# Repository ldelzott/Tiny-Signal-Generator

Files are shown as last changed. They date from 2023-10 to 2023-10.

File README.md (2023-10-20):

# Hobby-grade micro (PWM) signal generator made with off-the-shelve components
(Made in january 2023)

PWM signal generator based on an ESP32 microcontroller. The user can configure and customize individually each of the 16 PWM signals generated "simultaneously" by the device. The configuration is done via a physical & software user interface made of 4 push buttons and a 1.3" screen displaying a custom GUI. The electronic is encased in a 3D-printed plastic shell. The device can power standard 5mm LEDs or small servo motors (e.g. TowerPro SG90).  

## Plastic shell
The plastic pieces and the electronic are held together by friction. The pieces can be printed without any supports. 

platic_pieces

* A - gen_back_case.step
* B - gen_screen_upper_holder.step
* C - gen_screen_holder.step
* D - gen_pcb_separation.step
* E - gen_keypad_holder.step
* F - gen_keypad_lower_holder.step
* G - gen_front_case.step

## Electronic 
### Components
* [[DOC](https://docs.espressif.com/projects/esp-idf/en/latest/esp32/hw-reference/esp32/get-started-devkitc.html)] [[Components](https://www.amazon.fr/gp/aw/d/B071P98VTG/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)] ESP32-WROOM-32 Dev Kit C
* [DOC] [[Components](https://www.amazon.fr/daffichage-polychrome-cristaux-liquides-dentraînement/dp/B07QGQ1SR2/ref=sr_1_6?keywords=IPS+1.3"+240x240+with+ST7789&qid=1697656905&sr=8-6)] IPS 1.3" 240x240 with ST7789 controller.
* [DOC] [[Components](https://www.amazon.fr/ARCELI-Interface-IIC-Blindage-Raspberry/dp/B07RG9ZTMD/ref=sr_1_5?__mk_fr_FR=ÅMÅŽÕÑ&crid=3J0AZ9PUXPUG1&keywords=PCA9685+breakout+board&qid=1697656927&sprefix=pca9685+breakout+board%2Caps%2C59&sr=8-5)] PCA9685 breakout board
* [DOC] [[Components](https://www.amazon.fr/ARCELI-Interface-IIC-Blindage-Raspberry/dp/B07RG9ZTMD/ref=sr_1_5?__mk_fr_FR=ÅMÅŽÕÑ&crid=3J0AZ9PUXPUG1&keywords=PCA9685+breakout+board&qid=1697656927&sprefix=pca9685+breakout+board%2Caps%2C59&sr=8-5)] 4 Push buttons

### Schematic (draft)
wire_diagram_draftpng

### Specifications
Generate 16 PWM signals of 12-Bit at 1KHz, the PWM is reduced to 50Hz when at least one servo motor is attached & used.
When not disturbed by any user input, the generator outputs 50 points per second for each signal (50x16 points per second for the 16 signals). Each signal is made of 2048 points.   
## Overview
The device with the front case removed:

overview

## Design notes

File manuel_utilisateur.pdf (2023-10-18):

# Manuel

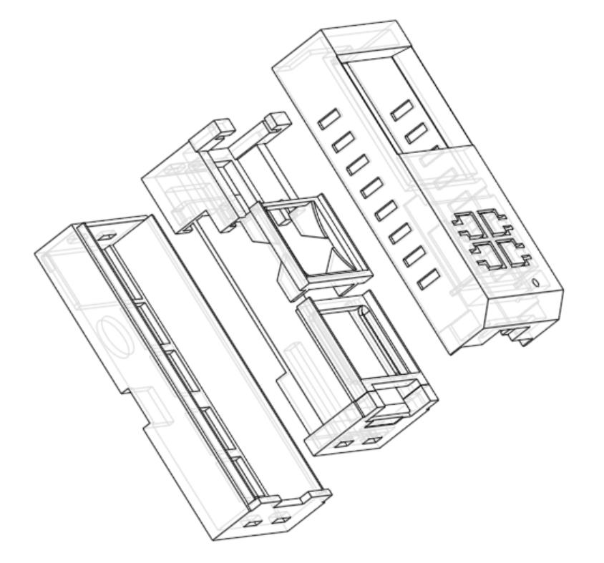
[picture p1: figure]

# Générateur de signaux 16-canaux pour LEDs & servo-moteurs

## Table des matières

## Intention

L’appareil permet de gérer jusqu’à 16 lumières (LEDs) et/ou moteurs à position programmable (SERVOs). Dans l’exemple d’une maquette d’avion, l’appareil peut être utilisé pour programmer le mouvement des volets ainsi que la séquence lumineuse des témoins de position. Il peut encore être utilisé pour réaliser des effets combinant lumières et/ou mouvements tel qu’un feu, ou encore animer des portes automatiques, des barrières, etc.

Note : l’appareil a pour vocation de permettre l’expérimentation dès lors qu’un mouvement ou un éclairage est requis pour une scène donnée. L’appareil ne devrait pas être utilisé comme une solution permanente.

## Informations complémentaires

Le générateur de signaux 16-canaux est un assemblage de pièces de plastique et de composants électroniques. Ces composants sont listés ci-après.

- Une carte de développement ESP32-WROOM-32 Dev Kit C.
- Un module d’affichage IPS 1.3’’ 240x240 pixels avec contrôleur ST7789 et interface SPI.
- Un module proposant 16 canaux PWM avec microcontrôleur PCA9685 et interface I2C.
- Un circuit comportant 4 boutons poussoir.

Un fois alimenté, l’assemblage permet de générer jusqu’à 16 signaux PWM simultanément. Chaque signal, configuré individuellement, est généré indépendamment des autres signaux. La configuration d’un signal s’effectue via l’écran et les boutons poussoir présent sur la face avant.

Note : PWM = Pulse Width Modulation.

## Alimentation

### Alimentation via port USB

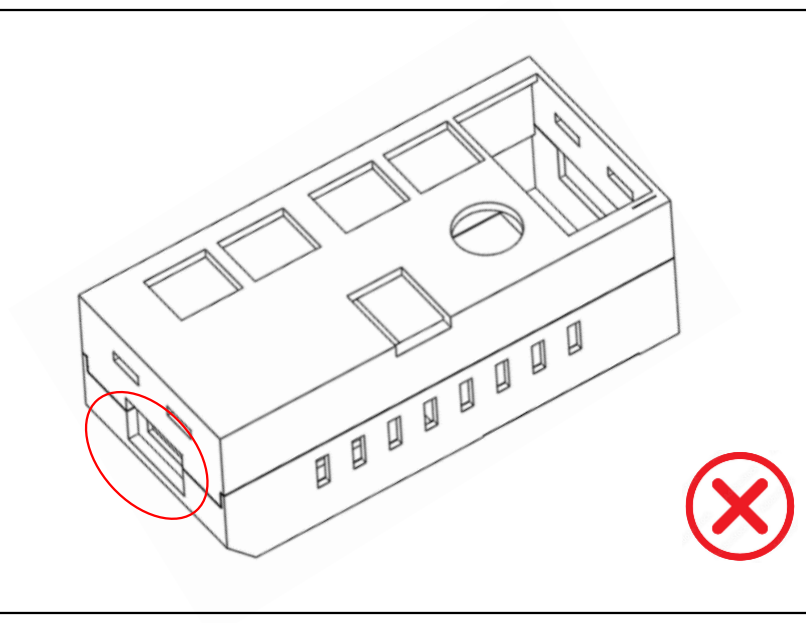
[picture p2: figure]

Le port USB permet de mettre à jour l’appareil. Le port USB ne doit pas être branché lors de l’utilisation : l’alimentation de l’appareil doit s’effectuer par le serre-fils (sucre) vert situé sur sa face arrière.

### Alimentation via serre-fils

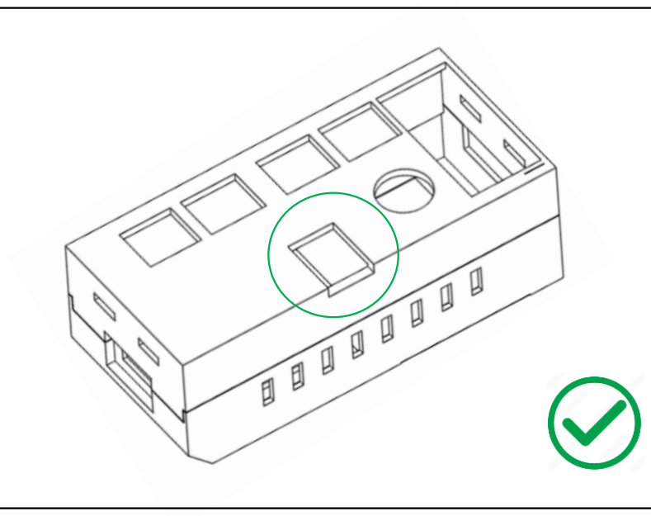
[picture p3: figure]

Le générateur doit être raccordé à une source de tension de 5V (continue) via le serre-fils vert. La borne de terre/masse est mise en surbrillance à l’indélébile noir. La consommation électrique de l’appareil varie en fonction du nombre de LED et/ou servo-moteurs connectés. Lorsque aucun composant ne lui est connecté, l’appareil consomme environ 110 mA.

### Dommages irréversibles en cas d’inversion de polarité

L’appareil n’est pas protégé contre les inversions de polarité.

## Branchements des composants

Le branchement des composants s’effectue via les ports situés sur la face arrière de l’appareil.

### Identification des ports

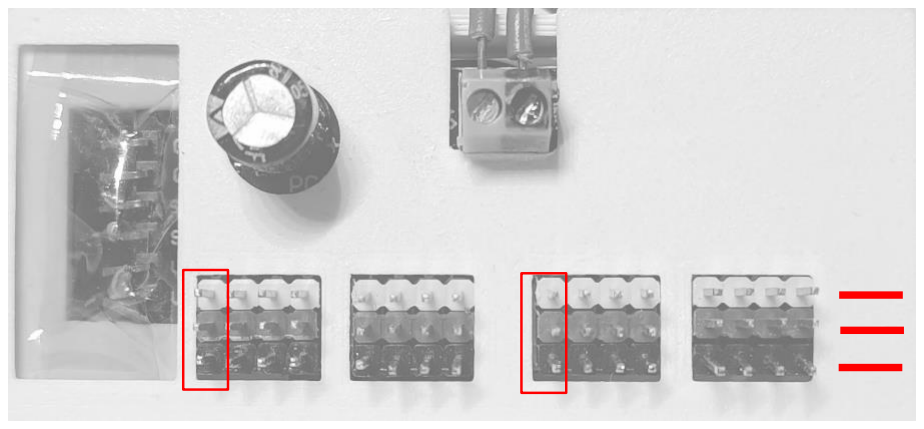
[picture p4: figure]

### Exemple de connexion – LED 5mm classique

La cathode (-) et l’anode (+) se connecte respectivement à la broche noire et jaune d’un port.

### Exemple de connexion – Servo moteur TowerPro SG90

Le fil brun, rouge et jaune du servo moteur se connecte respectivement à la broche noire, rouge et jaune d’un port.

### Caractéristiques technique des ports

En théorie, un port ne peut délivrer un courant supérieur à 25mA. Cette limite, fournie par le fabricant d’un des modules qui constitue l’appareil, n’a pas été testée en pratique. Idéalement, le branchement d’un composant ne devrait se faire qu’après configuration et vérification du signal généré sur un port donné.

0V (noir)

Port 1 | Port 9

5V 0V

5V (rouge)

PWM (jaune)

## Navigation

Description de la fonction de chaque bouton poussoir.

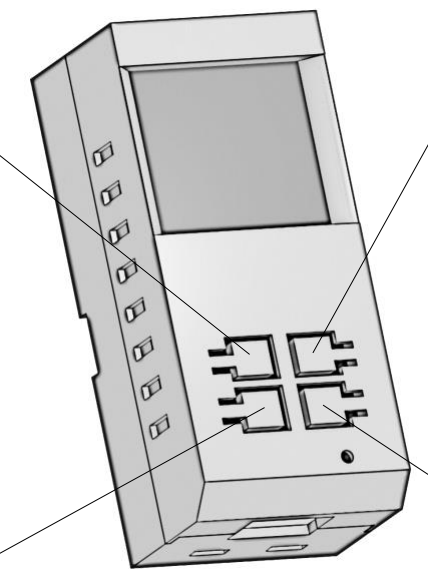
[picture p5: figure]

## Configurer un signal (pour LED/Lumière)

Cette section décrit les étapes nécessaires à la configuration d’un nouveau signal pour le port 1.

Example – Créer un signal sinusoïdal sur le port 1.
La touche NAV est utilisée pour parcourir les éléments des menus. La touche SELECT/DIV sélectionne l’élément souhaité.
1. Dans le menu principal, la « scene » fait référence à l’ensemble des signaux générés.
2. Les ports sont numérotés de 1 à 16. A chaque port est associée 3 broches visibles sur la face arrière.

NAV

Les différents éléments qui constituent un menu sont
accessibles par appuis
répétés sur la touche de
navigation

MINUS(-)
Lorsque l’élément mis en
surbrillance comporte un champ de valeur, la touche minus (-) réduit la valeur correspondante.

SELECT/DIV

Permet de sélectionner un élément. Lorsque l’élément comporte un champ de valeur, la fonction DIV permet de modifier la quantité ajoutée/retirée par les touches MINUS(-)/PLUS(+).

PLUS(+)

Lorsque l’élément
sélectionné comporte un
champ de valeur, la touche plus (+) augmente la valeur correspondante.

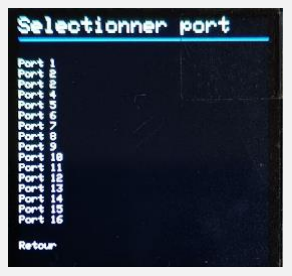
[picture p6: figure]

3. Le choix du port est effectué par appuis successifs sur la touche NAV.

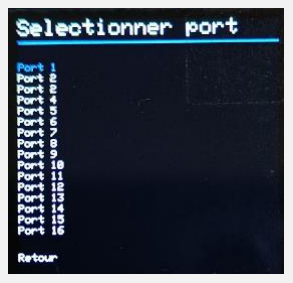
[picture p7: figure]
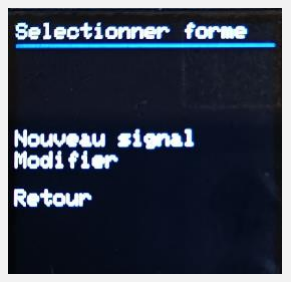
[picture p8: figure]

4. La sélection du port est effectuée à l’aide de la touche SELECT/DIV.

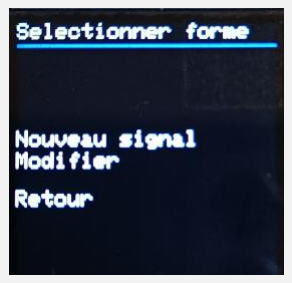
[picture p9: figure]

5. Le signal attribué au port sélectionné précédemment peut être remis à zéro ou modifié avec l’éditeur de signaux.

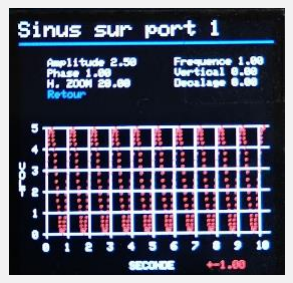
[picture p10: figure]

6. Le signal par défaut est une sinusoïde d’amplitude 2,5V et de fréquence 1Hz, centrée sur 2,5V. L’élément « Retour » est le premier élément mis en surbrillance lors de l’accès à ce menu.

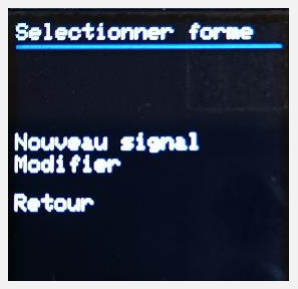
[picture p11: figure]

7. Sélectionner « Retour » permet d’enregistrer en mémoire le nouveau signal.

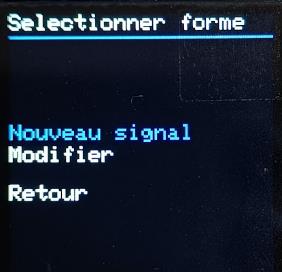
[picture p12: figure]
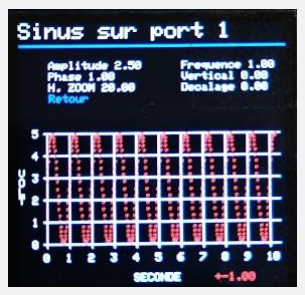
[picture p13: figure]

Etapes 1 à 7 : résultat
L’intensité lumineuse d’une LED branchée sur le port 1 devrait varier dans le temps de façon sinusoïdale. La LED s’allume complètement et s’éteint complètement toute les secondes (1Hz).

Example – Créer un signal constant sur le port 1.
Un signal constant peut être obtenu en créant une sinusoïde de fréquence 0Hz.

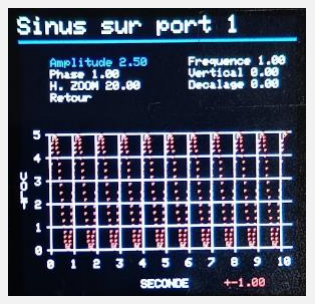
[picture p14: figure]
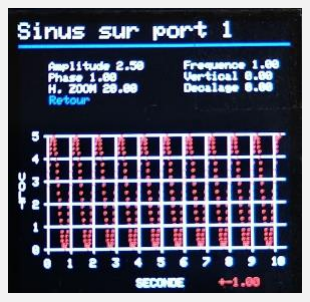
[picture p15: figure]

8. Une fois arrivé au point 6 décrit ci-avant, utiliser le bouton NAV pour mettre en surbrillance l’élément intitulé « Fréquence »

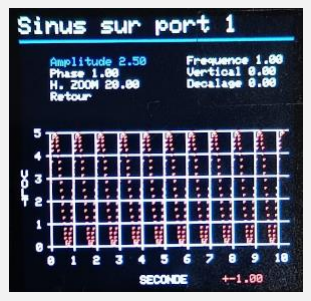
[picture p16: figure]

9.

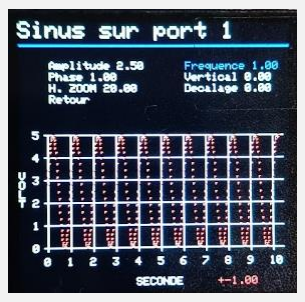
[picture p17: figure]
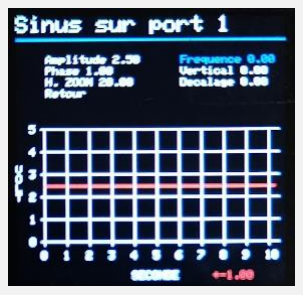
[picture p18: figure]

8. Réduire la fréquence à 0Hz.

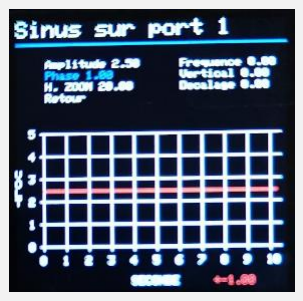
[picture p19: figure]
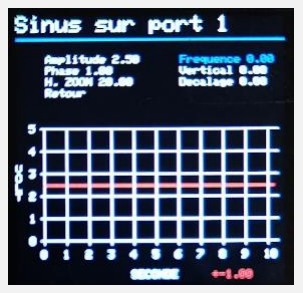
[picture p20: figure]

9.Naviguer jusque l’élément l’intitulé « vertical ».

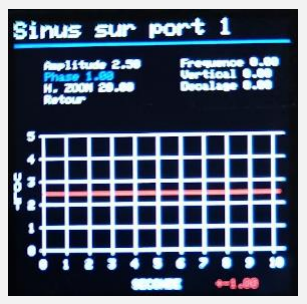
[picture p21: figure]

10.

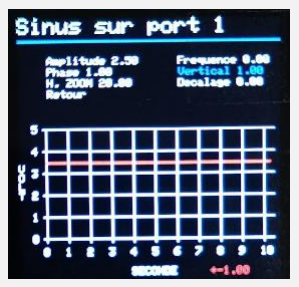
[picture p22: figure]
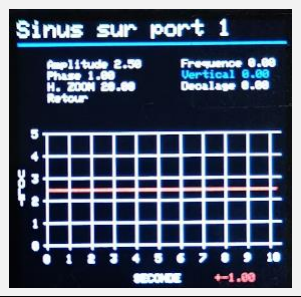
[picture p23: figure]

11. Les touches PLUS(+) et MINUS(-) peuvent être utilisées pour diminuer ou augmenter la tension du signal. Sélectionner ensuite l’élément intitulé « Retour » pour enregistrer les modifications.

Etapes 8 à 11 : résultat
L’intensité lumineuse d’une LED branchée sur le port 1 ne devrait plus varier dans le temps.

## Modifier un signal (pour LED/Lumière et Servo moteurs)

Une fois configuré, tout signal sinusoïdal ou constant peut être personnalisé grâce à l’éditeur de signaux. Dans le cas du signal associé au port 1, l’éditeur est accessible en sélectionnant l’élément intitulé « Modifier » dans le menu illustré au point 5 du tableau ci-avant.

### Fonctionnalités de l’éditeur

L’éditeur propose plusieurs outils pour affiner la forme des signaux ou modifier la façon dont ils sont affichés par l’écran. Le signal est mis à jour en temps réel. Les modifications sont enregistrées en sélectionnant l’élément « Retour ».

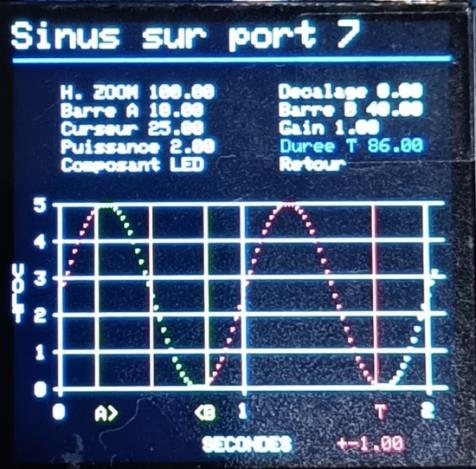
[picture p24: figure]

Visualisation et durée du signal
- HZOOM : permet d’augmenter ou de diminuer le nombre de secondes illustrées à l’écran.
- Decalage : permet de se déplacer sur l’axe du temps. Ce déplacement n’est pas quantifié en seconde.
- Duree T : permet de définir la durée maximale du signal. Une fois la durée expirée, la lecture du signal recommence à 0 seconde. Cette durée n’est pas quantifiée en seconde.

Modifier/affiner un signal
- Composant : permet de sélectionner un type de composant. Les deux types disponibles sont LED et SERVO. La LED est choisie comme composant par défaut. Le type SERVO permet de choisir l’angle (x36) ouvert par le moteur.
- Barre A : permet de déplacer la borne inférieure de la zone de sélection.
- Barre B : permet de déplacer la borne supérieure de la zone de sélection.
- Curseur : la distance entre les bornes AB et le curseur influence le comportement des outils « Gain » et « Puissance ».
- Gain/Puissance : multiplie par la valeur indiquée la partie du signal comprise entre les bornes A et B. Cette portion du signal est représentée par des points de couleur verte. Le gain est automatiquement divisé par la valeur produite par l’outil « Puissance ». La valeur configurée pour « Puissance » est placée en exposant (puissance) de la distance entre le curseur et ses bornes AB. Une puissance de 0 n’influence pas le résultat généré par l’outil Gain. La puissance peut être négative. La puissance peut être incluse entre 0 et 1.

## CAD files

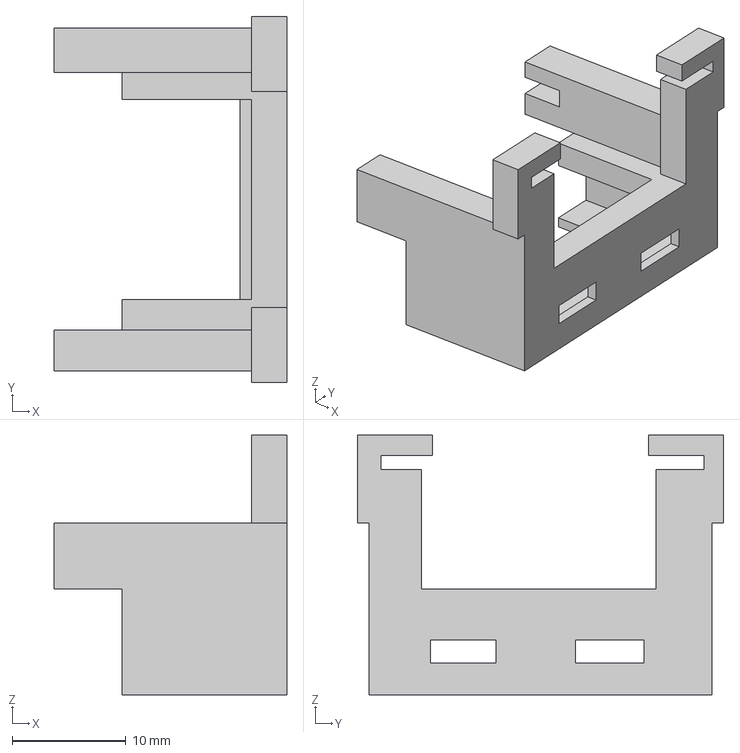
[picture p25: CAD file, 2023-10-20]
gen_screen_upper_holder.step
20.5 x 32.2 x 22.8 mm

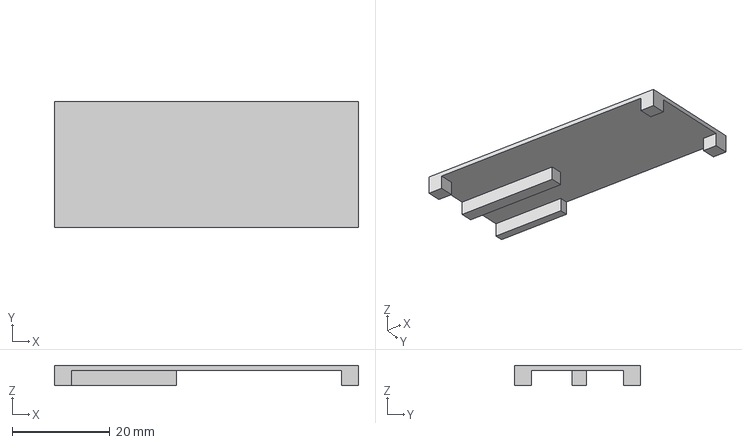
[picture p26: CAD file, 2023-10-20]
gen_pcb_separation.step
62.2 x 25.7 x 4.10 mm

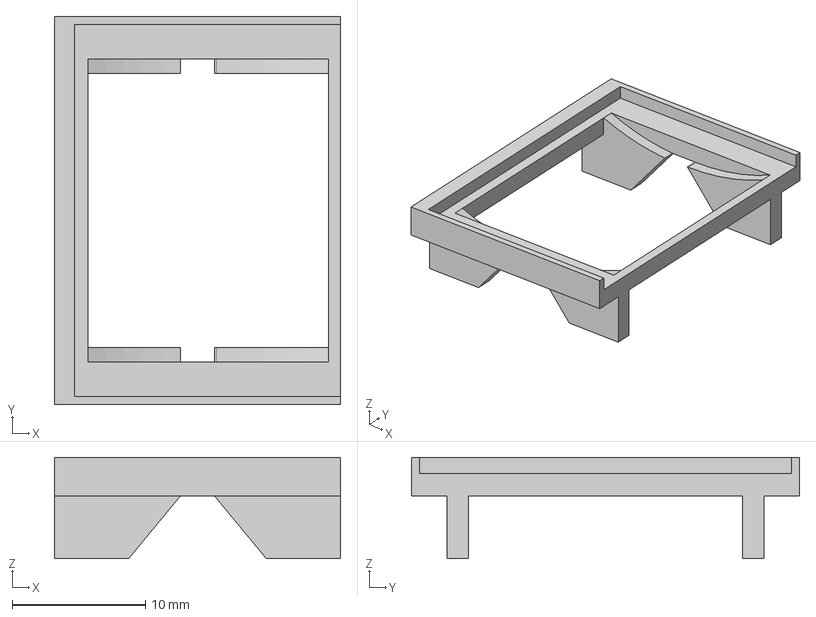
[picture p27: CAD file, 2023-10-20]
gen_screen_holder.step
21.5 x 29.2 x 7.60 mm

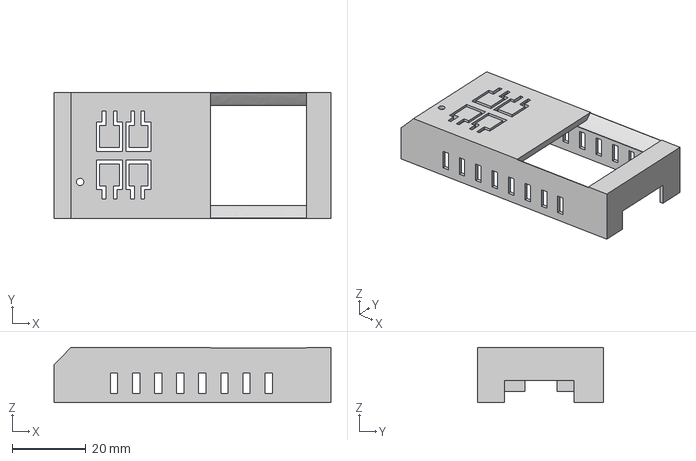
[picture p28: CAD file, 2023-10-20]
gen_front_case.step
75.3 x 34.3 x 15.0 mm

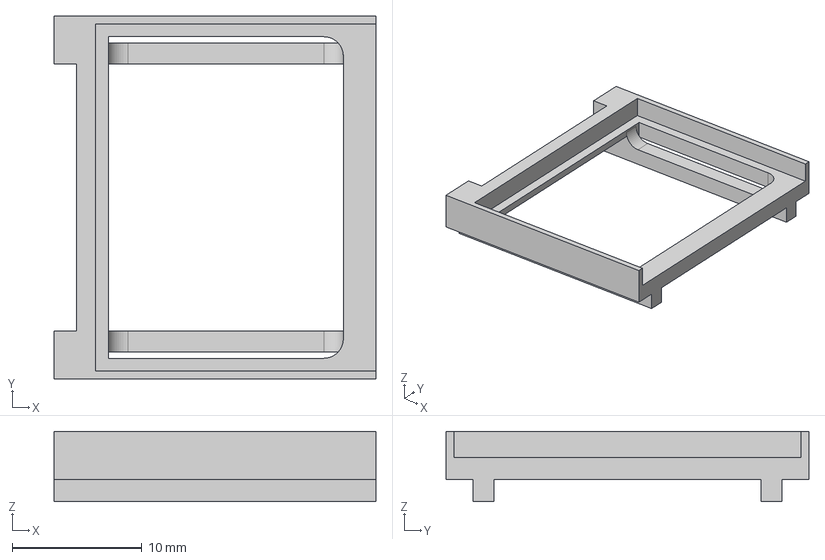
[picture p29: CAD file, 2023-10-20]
gen_keypad_holder.step
24.8 x 28.0 x 5.40 mm

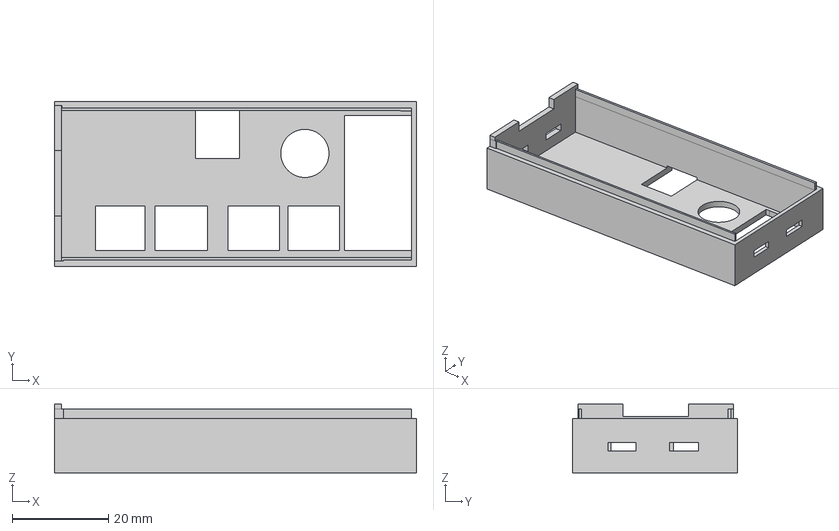
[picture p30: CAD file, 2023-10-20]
gen_back_case.step
75.3 x 34.3 x 14.3 mm

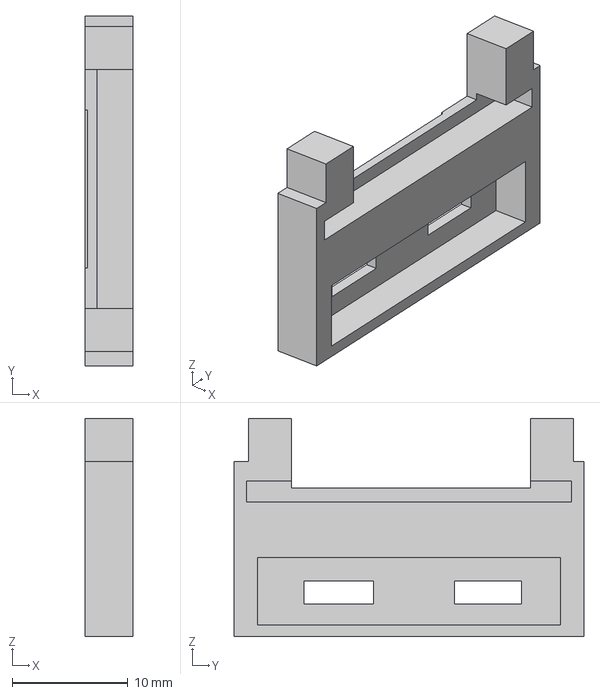
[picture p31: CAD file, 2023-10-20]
gen_keypad_lower_holder.step
4.10 x 30.2 x 18.8 mm

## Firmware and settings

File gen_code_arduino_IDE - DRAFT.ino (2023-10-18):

// TODO: Finishing sinus edit
// TODO: Adding Constant, Custome, Pure PWM editors
// TODO: Optional: Something could be wrong with the "selection" value of the "MenuScreen" struct: the value seems to be replaced by "-1" each time the menu is left.  
// TODO: Adding a bit of space between the "Return" item and the other items for aesthetic purpose.  
// TODO: Adding coarse/fine tuning in Sin editor
// TODO: Drawing the parametrized sine wave
// TODO: Adding pan view for the grid and the sine wave
// TODO: Avoiding overlapping of grid indications
// TODO: Adding value integrity check to avoid range overflow for specifics parameters
//        1. The MIN value for the HZOOM and VZOOM parameters of the sine waves should be set to 2 and 20. 
//        2. 
// TODO: Normalizing displayed barreA, barreB and cursor values by diving by "OPERATING_FREQUENCY"
// TODO: Scene time-length adjustements
// TODO: "Vertical" adjustement tool in "Nouveau Signal" menu works on the screen but does not seem to influence the port output.
// TODO: "Phase" adjustement tool in "Nouveau Signal" does seem to work for both the screen and the port output.


// The reported datatype memory size using Serial.println(sizeof([DATATYPE])) are as follow:
//    -> uint8_t        1 byte
//    -> uint16_t       2 bytes
//    -> int            4 bytes
//    -> unsigned int   4 bytes 
//    -> long           4 bytes
//    -> double         8 bytes

#include <FS.h>
#include "SPIFFS.h"
#include <TFT_eSPI.h> // Graphics and font library for ST7735 driver chip
#include <SPI.h>
#include <Wire.h>
#include <Adafruit_PWMServoDriver.h>

#include <cstring>

#define BOUNCING_DELAY 150 // Milliseconds of delay between two valid push-button entries

#define BUTTON_NAVIGATION_PIN 4
#define BUTTON_SELECTION_PIN 23
#define BUTTON_MINUS_PIN 15
#define BUTTON_PLUS_PIN 14

#define SIGNAL_NUMBER 16
#define SIGNAL_RESOLUTION 2048
#define SIGNAL_DEPTH_RESOLUTION 4095 // 12 bits
#define OPERATING_FREQUENCY 50
#define MAX_SYSTEM_VOLTAGE 5

#define DATATYPE_BYTESIZE 2
#define DATATYPE_UINT16_RANGE 65535

#define SIN_GRID_WIDTH 206 // Should be strictly less than 240
#define SIN_GRID_HEIGHT 100 // Should be strictly less than 240
#define SIN_GRID_X_OFFSET 25
#define SIN_GRID_Y_OFFSET 100
#define SIN_GRID_X_TEXT_SPACING 20
#define SIN_GRID_X_STEP_MIN 4
#define SIN_GRID_MAX_X_TRAVELLING_OFFSET 2048
#define SIN_GRID_MIN_X_TRAVELLING_OFFSET 0
#define SIN_DISTINCT_INCREMENT_VALUES 6 // Changing the "button_step_increment_values" array size accordingly when updating this value
#define SIN_INITIAL_INCREMENT_INDEX 2 // Should be strictly less than SIN_DISTINCT_INCREMENT_VALUES

#define LED_DEVICE_SELECTION 0
#define MOTOR_DEVICE_SELECTION 1
#define PWM_DUTY_RANGE 4094
#define PWM_PCA9685_OPERATING_FREQUENCY 1000
#define PWM_PCA9685_OPERATING_FREQUENCY_MOTOR 60 // Assuming 50Hz servo motors
#define SERVO_DEFAULT_MIN_DUTY 125
#define SERVO_DEFAULT_MAX_DUTY 575

/////////////////////// STRUCTS

struct PushButton {
  const uint8_t PIN;
  const int debounceDelay;
  unsigned long lastPress;
  bool state;
};

struct MenuScreen {
  char menuTitle[20];
  int selection;
  int selectionMax;
  bool hasReturnOption;
  int itemNumber;
  const char* itemList[17];
  int itemFontSize;
  int itemSpatialOffset;
  int lastItemOffset;
  bool isWelcomeScreen;
};

struct Signal {
  float amplitude;
  float frequency;
  float phase;
  float y_offset;
};



/////////////////////// BUTTON ISRs

PushButton button_navigation = {BUTTON_NAVIGATION_PIN, BOUNCING_DELAY, millis() + BOUNCING_DELAY, false};
PushButton button_selection = {BUTTON_SELECTION_PIN, BOUNCING_DELAY, millis() + BOUNCING_DELAY, false};
PushButton button_minus = {BUTTON_MINUS_PIN, BOUNCING_DELAY, millis() + BOUNCING_DELAY, false};
PushButton button_plus = {BUTTON_PLUS_PIN, BOUNCING_DELAY, millis() + BOUNCING_DELAY, false};

void IRAM_ATTR isr_navigation_button() {
  if ((millis() - button_navigation.lastPress) > button_navigation.debounceDelay && button_navigation.state == false) {
    button_navigation.state = true; button_navigation.lastPress = millis();
  }
}

void IRAM_ATTR isr_selection_button() {
  if ((millis() - button_selection.lastPress) > button_selection.debounceDelay && button_selection.state == false) {
    button_selection.state = true; button_selection.lastPress = millis();
  }
}

void IRAM_ATTR isr_minus_button() {
  if ((millis() - button_minus.lastPress) > button_minus.debounceDelay && button_minus.state == false) {
    button_minus.state = true; button_minus.lastPress = millis();
  }
}

void IRAM_ATTR isr_plus_button() {
  if ((millis() - button_plus.lastPress) > button_plus.debounceDelay && button_plus.state == false) {
    button_plus.state = true; button_plus.lastPress = millis();
  }
}


///////////////////// INITIALIZATION AND MAIN LOOP

MenuScreen welcomeScreen = {"Menu Principal", 
                            -1, 
                             2, 
                             false, 
                             2, 
                             {"Editer scene", "Visualiser scene"}, 
                             2,
                             110,
                             0, 
                             true};
                             
MenuScreen signalSelectionScreen = {"Selectionner port", 
                                    -1, 
                                    17, 
                                    true, 
                                    17, 
                                    {"Port 1", "Port 2", "Port 3", "Port 4", "Port 5","Port 6", "Port 7", "Port 8", "Port 9", "Port 10", "Port 11","Port 12", "Port 13", "Port 14", "Port 15", "Port 16", "Retour"},
                                    1, 
                                    40,
                                    15, 
                                    false};
                                    
MenuScreen formeSelectionScreen = {"Selectionner forme", 
                                    -1, 
                                    3, 
                                    true, 
                                    3, 
                                    {"Nouveau signal", "Modifier", "Retour"},
                                    2, 
                                    100,
                                    15, 
                                    false};

MenuScreen currentMenuScreen;

int screenID;
int selectedSignal;
int selectedShape;
int selectedShapes[16] = {0,0,0,0,0,0,0,0,0,0,0,0,0,0,0,0};


// 16xSIGNAL_RESOLUTIONx2 bytes gives:
//     -> 16x1024x2 bytes = 32768 bytes   = 32,7 Kbytes
//     -> 16x2048x2 bytes = 65535 bytes   = 65,5 Kbytes
//     -> 16x4096x2 bytes = 131072 bytes  = 131 Kbytes

uint16_t master_signal[SIGNAL_NUMBER][SIGNAL_RESOLUTION]; 
uint16_t master_signal_buffer[SIGNAL_RESOLUTION]; // Used when customizing a master_signal

float actual_button_step_increment_value;
int button_step_index=SIN_INITIAL_INCREMENT_INDEX;
float button_step_increment_values[SIN_DISTINCT_INCREMENT_VALUES]={0.01,0.1,1,10,100,1000};


int sin_selectedParameter;
String sin_signalParamsNames[] = {"Amplitude", "Frequence", "Phase", "Vertical", "H. ZOOM", "Decalage", "Retour"};
int sin_numberOfParams = 6;
float sin_signalParams[16][7] = { {2.5, 1.0, 1, 0, 20, 0, 20}, 
                                  {2.5, 1.0, 1, 0, 20, 0, 20},
                                  {2.5, 1.0, 1, 0, 20, 0, 20},
                                  {2.5, 1.0, 1, 0, 20, 0, 20},
                                  {2.5, 1.0, 1, 0, 20, 0, 20},
                                  {2.5, 1.0, 1, 0, 20, 0, 20},
                                  {2.5, 1.0, 1, 0, 20, 0, 20},
                                  {2.5, 1.0, 1, 0, 20, 0, 20},
                                  {2.5, 1.0, 1, 0, 20, 0, 20},
                                  {2.5, 1.0, 1, 0, 20, 0, 20},
                                  {2.5, 1.0, 1, 0, 20, 0, 20},
                                  {2.5, 1.0, 1, 0, 20, 0, 20},
                                  {2.5, 1.0, 1, 0, 20, 0, 20},
                                  {2.5, 1.0, 1, 0, 20, 0, 20},
                                  {2.5, 1.0, 1, 0, 20, 0, 20},
                                  {2.5, 1.0, 1, 0, 20, 0, 20}};

int viz_selectedParameter;
String viz_signalParamsNames[] = {"H. ZOOM", "Decalage", "Signal", "Retour"};
int viz_numberOfParams = 3;
float viz_signalParams[4] = {20, 0, 0, 20};

int constant_device_selection;
int constant_selectedParameter;
String constant_signalParamsNames[] = {"H. ZOOM", "Decalage", "Barre A", "Barre B", "Curseur", "Gain", "Puissance", "Duree T", "Composant", "Retour"}; // Do not change the "Composant" position in the array. 
int constant_numberOfParams = 9;
float constant_signalParams[16][9] = {{100, 0, 10, 40, 25, 1, 2, OPERATING_FREQUENCY*2, LED_DEVICE_SELECTION}, 
                                      {100, 0, 10, 40, 25, 1, 2, OPERATING_FREQUENCY*2, LED_DEVICE_SELECTION},
                                      {100, 0, 10, 40, 25, 1, 2, OPERATING_FREQUENCY*2, LED_DEVICE_SELECTION},
                                      {100, 0, 10, 40, 25, 1, 2, OPERATING_FREQUENCY*2, LED_DEVICE_SELECTION},
                                      {100, 0, 10, 40, 25, 1, 2, OPERATING_FREQUENCY*2, LED_DEVICE_SELECTION},
                                      {100, 0, 10, 40, 25, 1, 2, OPERATING_FREQUENCY*2, LED_DEVICE_SELECTION},
                                      {100, 0, 10, 40, 25, 1, 2, OPERATING_FREQUENCY*2, LED_DEVICE_SELECTION},
                                      {100, 0, 10, 40, 25, 1, 2, OPERATING_FREQUENCY*2, LED_DEVICE_SELECTION},
                                      {100, 0, 10, 40, 25, 1, 2, OPERATING_FREQUENCY*2, LED_DEVICE_SELECTION},
                                      {100, 0, 10, 40, 25, 1, 2, OPERATING_FREQUENCY*2, LED_DEVICE_SELECTION},
                                      {100, 0, 10, 40, 25, 1, 2, OPERATING_FREQUENCY*2, LED_DEVICE_SELECTION},
                                      {100, 0, 10, 40, 25, 1, 2, OPERATING_FREQUENCY*2, LED_DEVICE_SELECTION},
                                      {100, 0, 10, 40, 25, 1, 2, OPERATING_FREQUENCY*2, LED_DEVICE_SELECTION},
                                      {100, 0, 10, 40, 25, 1, 2, OPERATING_FREQUENCY*2, LED_DEVICE_SELECTION},
                                      {100, 0, 10, 40, 25, 1, 2, OPERATING_FREQUENCY*2, LED_DEVICE_SELECTION},
                                      {100, 0, 10, 40, 25, 1, 2, OPERATING_FREQUENCY*2, LED_DEVICE_SELECTION}};



int PWM_frequency_toggle = 0;

TFT_eSPI tft = TFT_eSPI();
Adafruit_PWMServoDriver PCA9685 = Adafruit_PWMServoDriver(0x40, Wire);

void flash_data_loading_screen(){
  tft.fillScreen(TFT_BLACK);
  tft.setTextSize(2);             // set text size to 2
  tft.setCursor(12, tft.height()/2-50);            // set cursor position
  tft.setTextColor(TFT_WHITE);
  tft.println("Lecture memoire...");           // print "Menu" at the top of the screen
  tft.drawLine(tft.width(), tft.height()/2.0-15-40, 0, tft.height()/2.0-15-40, TFT_WHITE);
  tft.drawLine(tft.width(), tft.height()/2.0+10-40, 0, tft.height()/2.0+10-40, TFT_WHITE);
}

void flash_data_writting_screen(){
  tft.fillScreen(TFT_BLACK);
  //tft.fillRect( 0,tft.height()/2.0-15, tft.width(), 25,TFT_BLACK);
  tft.setTextSize(2);             // set text size to 2
  tft.setCursor(12, tft.height()/2-50);            // set cursor position
  tft.setTextColor(TFT_WHITE);
  tft.println("Enregistrement...");           // print "Menu" at the top of the screen
  tft.drawLine(tft.width(), tft.height()/2.0-15-40, 0, tft.height()/2.0-15-40, TFT_WHITE);
  tft.drawLine(tft.width(), tft.height()/2.0+10-40, 0, tft.height()/2.0+10-40, TFT_WHITE);
}

void retrieve_data_from_flash(){
  flash_data_loading_screen();
  if(!SPIFFS.begin(true)){ // Argument should be false but works anyway... 
    Serial.println("An Error has occurred while mounting SPIFFS");
    return;
  }
  File opened_file = SPIFFS.open("/masterSignal.bin", "r");
  if (!opened_file) {
    Serial.println("An Error has occurred while opening file for reading");
    return;
  }
  opened_file.read((uint8_t*)master_signal, sizeof(master_signal));
  opened_file.close();
  SPIFFS.end();
}


void write_data_to_flash(){
  flash_data_writting_screen();
  if(!SPIFFS.begin(true)){ // Argument should be false but works anyway... 
    Serial.println("An Error has occurred while mounting SPIFFS");
    return;
  }
  
  File file = SPIFFS.open("/masterSignal.bin", "w");
  if (!file) {
    Serial.println("An Error has occurred while opening file for writing");
    return;
  }
  file.write((uint8_t*)master_signal, sizeof(master_signal));
  file.close();
  SPIFFS.end();
}

void resetButtons(){
  button_selection.state = false;
  button_navigation.state = false;
  button_plus.state = false;
  button_minus.state = false;
  tft.fillScreen(TFT_BLACK);
}


void drawMenuScreen(){
  int lastItemOffset = 0;
  tft.setTextSize(2);             // set text size to 2
  tft.setCursor(0, 0);            // set cursor position
  tft.setTextColor(TFT_WHITE);
  tft.println(currentMenuScreen.menuTitle);           // print "Menu" at the top of the screen
  tft.drawLine(tft.width(), 20, 0, 20, TFT_BLUE);
  tft.drawLine(tft.width(), 21, 0, 21, TFT_BLUE);
  tft.setTextSize(currentMenuScreen.itemFontSize); 
  for (int i = 0; i < currentMenuScreen.selectionMax; i++) {
    if( i == currentMenuScreen.selectionMax-1){
      lastItemOffset = currentMenuScreen.lastItemOffset;
    }
    tft.setCursor(0, currentMenuScreen.itemSpatialOffset + i*10*currentMenuScreen.itemFontSize + lastItemOffset);
    if (i == currentMenuScreen.selection) {
      tft.setTextColor(TFT_BLUE);
    } else {
      tft.setTextColor(TFT_WHITE);
    }
    tft.println(currentMenuScreen.itemList[i]);
  }
  if (currentMenuScreen.isWelcomeScreen){
    tft.setTextColor(TFT_WHITE);
    tft.setCursor(200, 220);
    tft.setTextSize(1);
    tft.println("v1.0");
  }
  tft.setTextColor(TFT_WHITE);
}



void new_sinewave_initialization(){
  
  float phase = sin_signalParams[selectedSignal][2] * OPERATING_FREQUENCY; // Allows to define the phase in seconds instead of graph points 
  float vertical_shift = (-1) * sin_signalParams[selectedSignal][3] * (float)(DATATYPE_UINT16_RANGE/MAX_SYSTEM_VOLTAGE); // Volt-wise steps
  float frequency = 2*PI*sin_signalParams[selectedSignal][1] / OPERATING_FREQUENCY; // A sine frequency of one Hz is made of OPERATING_FREQUENCY discrete points since the since the system runs at OPERATING_FREQUENCY Hz.      
  float amplitude = (sin_signalParams[selectedSignal][0]*2) / MAX_SYSTEM_VOLTAGE; // The x2 account for the amplitude measure of the sine wave (i.e half of the total vertical span of the signal) 
 
  
  for(int i=0; i<SIGNAL_RESOLUTION; i++){
    // The sine wave has a vertical offset since the datatype uint16_t does not seem to handle signed numbers.
    // To avoid loosing in height resolution at this stage of the code, the provided signal should fill the 65535 values of uint16_t datatype
    int sin_value_without_overflow = ( amplitude * (float)(DATATYPE_UINT16_RANGE/2) * (1+sin((i+phase)*frequency)) - vertical_shift );
    if(sin_value_without_overflow>=DATATYPE_UINT16_RANGE-1){
      master_signal[selectedSignal][i] = DATATYPE_UINT16_RANGE - 1;
    } else if (sin_value_without_overflow<=0){
      master_signal[selectedSignal][i] = 0;
    } else{
      master_signal[selectedSignal][i] = (uint16_t)sin_value_without_overflow;
    }
    //Serial.println(master_signal[selectedSignal][i]);
  }
}

void drawNewSignal(){
  
  float number_of_fetched_points = ((float)SIN_GRID_WIDTH/sin_signalParams[selectedSignal][4])*(float)OPERATING_FREQUENCY;
  float pixel_distance = SIN_GRID_WIDTH/number_of_fetched_points;
  float index_value = sin_signalParams[selectedSignal][5] / pixel_distance;
  
  for(float i=0; i<number_of_fetched_points; i++){
    index_value++;
    if ( index_value < SIGNAL_RESOLUTION ){
      int normalized_to_screen = int( ( (DATATYPE_UINT16_RANGE-(float)master_signal[selectedSignal][(int)index_value]) / (float)DATATYPE_UINT16_RANGE ) * (float)SIN_GRID_HEIGHT );
      int center_graph_offset = 0;// int((MAX_SYSTEM_VOLTAGE - (float)sin_signalParams[selectedSignal][0]*2)/MAX_SYSTEM_VOLTAGE * (float)SIN_GRID_HEIGHT)/2;
      tft.drawPixel(SIN_GRID_X_OFFSET+(int)(i*pixel_distance), SIN_GRID_Y_OFFSET+center_graph_offset+normalized_to_screen, TFT_RED);
      tft.drawPixel(SIN_GRID_X_OFFSET+(int)(i*pixel_distance), SIN_GRID_Y_OFFSET+center_graph_offset+normalized_to_screen+1, TFT_RED); // Double the pixel height of the line to make it more visible on the screen
      tft.drawPixel(SIN_GRID_X_OFFSET+(int)(i*pixel_distance)+1, SIN_GRID_Y_OFFSET+center_graph_offset+normalized_to_screen, TFT_RED); // Double the pixel width of the line to make it more visible on the screen
    }
  } 
 
}

void drawNewSignal_viz(){
  selectedSignal = int(viz_signalParams[2]);
  float number_of_fetched_points = ((float)SIN_GRID_WIDTH/viz_signalParams[0])*(float)OPERATING_FREQUENCY;
  float pixel_distance = SIN_GRID_WIDTH/number_of_fetched_points;
  float index_value = viz_signalParams[1] / pixel_distance;
  
  for(float i=0; i<number_of_fetched_points; i++){
    index_value++;
    if ( index_value < SIGNAL_RESOLUTION ){
      int normalized_to_screen = int( ( (DATATYPE_UINT16_RANGE-(float)master_signal[selectedSignal][(int)index_value]) / (float)DATATYPE_UINT16_RANGE ) * (float)SIN_GRID_HEIGHT );
      int center_graph_offset = 0;// int((MAX_SYSTEM_VOLTAGE - (float)sin_signalParams[selectedSignal][0]*2)/MAX_SYSTEM_VOLTAGE * (float)SIN_GRID_HEIGHT)/2;
      tft.drawPixel(SIN_GRID_X_OFFSET+(int)(i*pixel_distance), SIN_GRID_Y_OFFSET+center_graph_offset+normalized_to_screen, TFT_RED);
      tft.drawPixel(SIN_GRID_X_OFFSET+(int)(i*pixel_distance), SIN_GRID_Y_OFFSET+center_graph_offset+normalized_to_screen+1, TFT_RED); // Double the pixel height of the line to make it more visible on the screen
      tft.drawPixel(SIN_GRID_X_OFFSET+(int)(i*pixel_distance)+1, SIN_GRID_Y_OFFSET+center_graph_offset+normalized_to_screen, TFT_RED); // Double the pixel width of the line to make it more visible on the screen
    }
  } 
 
}

void drawSinGrid(){ 
  
  tft.setTextColor(TFT_WHITE);
  
  int gridStep_x = int(sin_signalParams[selectedSignal][4]);
  int gridStep_y = 20 ; // int(sin_signalParams[selectedSignal][6]);
  int gridStep_x_travelling_offset = int(sin_signalParams[selectedSignal][5]);
  int voltage_division=0;
  int time_division=0;
  int delta_x = SIN_GRID_X_TEXT_SPACING; // Init value to see the "0" marking
  int x_old = 0;

  tft.setTextSize(1);             // set text size to 2
  tft.setCursor(SIN_GRID_X_OFFSET+3, SIN_GRID_Y_OFFSET + int(SIN_GRID_HEIGHT/2) - 25);
  tft.println(""); tft.println("V");  tft.println("O"); tft.println("L"); tft.println("T"); 
  tft.setCursor(SIN_GRID_X_OFFSET + int(SIN_GRID_WIDTH/2) - 25, SIN_GRID_Y_OFFSET + SIN_GRID_HEIGHT + 27);
  tft.println("SECONDE");
  tft.setCursor(SIN_GRID_X_OFFSET + SIN_GRID_WIDTH-55, SIN_GRID_Y_OFFSET + SIN_GRID_HEIGHT + 27);
  tft.setTextColor(TFT_RED);
  tft.println("+-"+String(actual_button_step_increment_value));
  tft.setTextColor(TFT_WHITE);
  
  // Draw the vertical lines
  for (int x = -gridStep_x_travelling_offset; x <= SIN_GRID_WIDTH+gridStep_x_travelling_offset; x += gridStep_x) {
    if (x<=SIN_GRID_X_OFFSET-30){
      time_division++;
      continue;
    }
    if (x>=SIN_GRID_X_OFFSET+SIN_GRID_WIDTH-20){
      time_division++;
      continue;
    }
    delta_x = delta_x + (x-x_old); // Managing the spacing between the x grid annotations. 
    if (delta_x >= SIN_GRID_X_TEXT_SPACING){
      tft.setCursor(x+SIN_GRID_X_OFFSET-3, SIN_GRID_HEIGHT+SIN_GRID_Y_OFFSET+9);
      tft.print(String(time_division));
      delta_x=0;
      tft.drawLine(x+SIN_GRID_X_OFFSET, SIN_GRID_Y_OFFSET, x+SIN_GRID_X_OFFSET, SIN_GRID_HEIGHT+SIN_GRID_Y_OFFSET+3, TFT_WHITE); // The "3" value here serves a as "mark" for the corresponding text annotation. 
    } else {
      tft.drawLine(x+SIN_GRID_X_OFFSET, SIN_GRID_Y_OFFSET, x+SIN_GRID_X_OFFSET, SIN_GRID_HEIGHT+SIN_GRID_Y_OFFSET, TFT_WHITE);
    }
    x_old = x;
    time_division++;
  }

  // Draw the horizontal lines
  for (int y = SIN_GRID_HEIGHT; y >= 0; y -= gridStep_y) {
    tft.drawLine(SIN_GRID_X_OFFSET-3, y+SIN_GRID_Y_OFFSET, SIN_GRID_WIDTH + SIN_GRID_X_OFFSET+3, y+SIN_GRID_Y_OFFSET, TFT_WHITE);
    tft.setCursor(SIN_GRID_X_OFFSET-13, y+SIN_GRID_Y_OFFSET-3);
    tft.print(String(voltage_division));
    voltage_division++;
  }
  
  new_sinewave_initialization();
  drawNewSignal();

}
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
void loop() {
  
    monitoring_clock_start = millis();
    
    if (main_signal_time_counter >= SIGNAL_RESOLUTION){
      main_signal_time_counter = 0;
    }
    check_user_input();

    for(int i = 0; i<SIGNAL_NUMBER; i++){
      if(constant_signalParams[i][8] == LED_DEVICE_SELECTION){
        PCA9685.setPWM(i,0,(int)(((float)master_signal[i][main_signal_time_counter%(int)constant_signalParams[i][7]]/((float)DATATYPE_UINT16_RANGE))*PWM_DUTY_RANGE));
      } else {
        PCA9685.setPWM(i,0,map((int)(((float)master_signal[i][main_signal_time_counter%(int)constant_signalParams[i][7]]/((float)DATATYPE_UINT16_RANGE))*PWM_DUTY_RANGE), 0, PWM_DUTY_RANGE, SERVO_DEFAULT_MIN_DUTY, SERVO_DEFAULT_MAX_DUTY));
        Serial.println(map((int)(((float)master_signal[i][main_signal_time_counter%(int)constant_signalParams[i][7]]/((float)DATATYPE_UINT16_RANGE))*PWM_DUTY_RANGE), 0, PWM_DUTY_RANGE, SERVO_DEFAULT_MIN_DUTY, SERVO_DEFAULT_MAX_DUTY));
      }
        
    }

    main_signal_time_counter++;
    
    monitoring_clock_stop = millis();
    remaining_slack_time = monitoring_clock_stop-monitoring_clock_start;
    
    if (remaining_slack_time<task_duration){
      delay(task_duration-remaining_slack_time);
      //Serial.print("Slack: "); Serial.print(task_duration-remaining_slack_time); Serial.println(" ms");
    }
    
    
  
}
